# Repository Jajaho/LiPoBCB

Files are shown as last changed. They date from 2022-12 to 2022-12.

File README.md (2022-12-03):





---
## Artifacts

[Docs](https://github.com/Jajaho/LiPoBCB/suites/9631889772/artifacts/460196864)  
[Images](https://github.com/Jajaho/LiPoBCB/suites/9631889772/artifacts/460196866)  
[CAD](https://github.com/Jajaho/LiPoBCB/suites/9631889772/artifacts/460196863)  
[Gerber](https://github.com/Jajaho/LiPoBCB/suites/9631889772/artifacts/460196865)

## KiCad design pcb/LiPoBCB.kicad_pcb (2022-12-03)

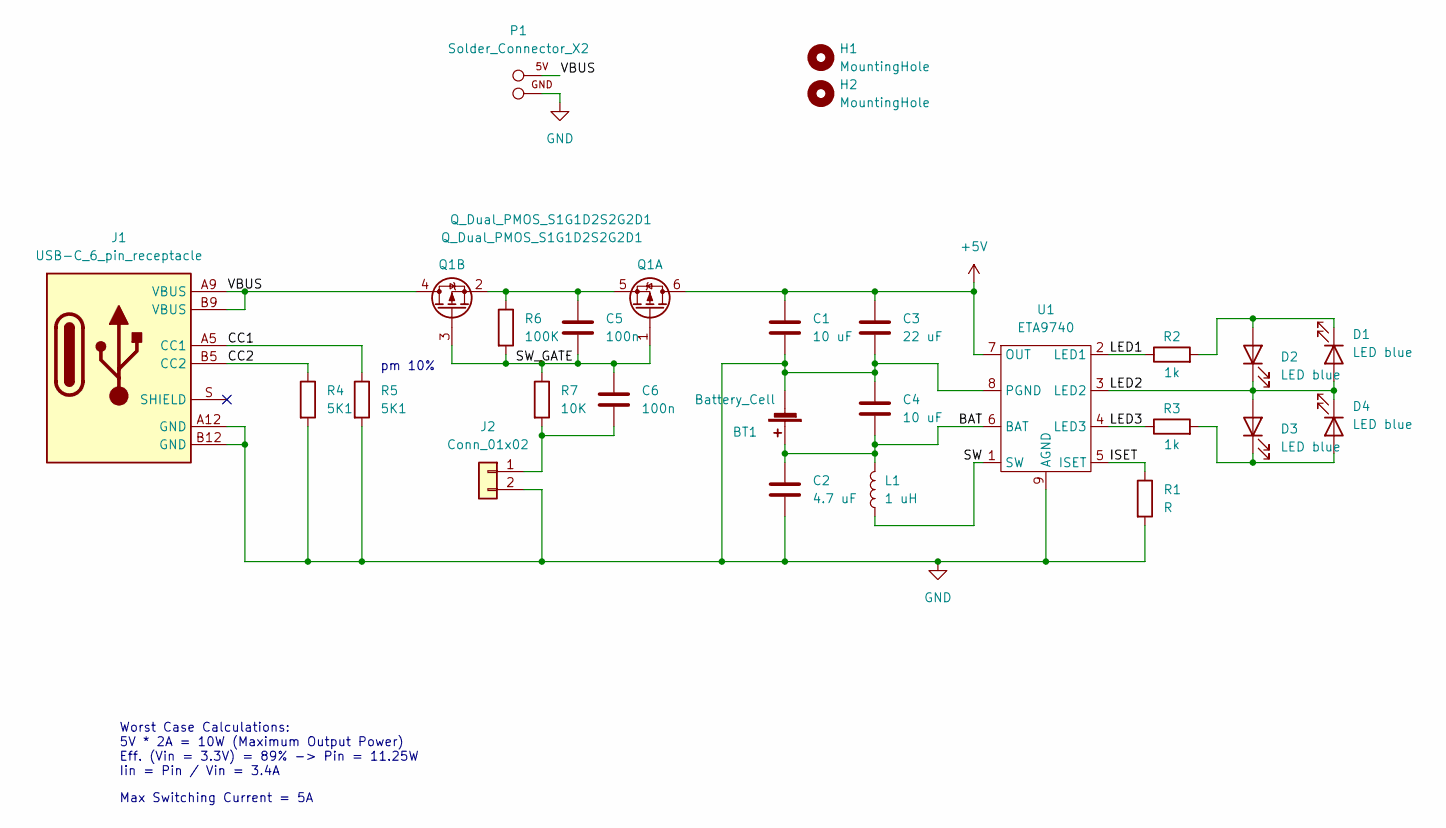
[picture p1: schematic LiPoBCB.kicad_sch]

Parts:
BT1: Battery_Cell; JST_PH_B2B-PH-K_1x02_P2.00mm_Vertical
C1, C4: 10 uF; C_0603_1608Metric
C2: 4.7 uF; C_0603_1608Metric
C3: 22 uF; C_0805_2012Metric
C5, C6: 100n; C_0603_1608Metric
D1, D2, D3, D4: LED blue; D_0603_1608Metric
H1, H2: MountingHole; MountingHole_2.2mm_M2_ISO14580
J1: USB-C_6_pin_receptacle; Korean Hroparts Elec TYPE-C-31-M-17
J2: Conn_01x02; Solder_Connector_SW
L1: 1 uH; L_smd_1616
P1: Solder_Connector_X2
Q1: Q_Dual_PMOS_S1G1D2S2G2D1; SOT-23-6
R1: R; R_0603_1608Metric
R2, R3: 1k; R_0603_1608Metric
R4, R5: 5K1; R_0603_1608Metric
R6: 100K; R_0603_1608Metric
R7: 10K; R_0603_1608Metric
U1: ETA9740; SOIC-8-1EP_3.9x4.9mm_P1.27mm_EP2.29x3mm

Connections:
+5V: C1.1, C3.1, Q1.6 (D), U1.7 (OUT)
/BAT: BT1.1 (+), C2.1, C4.2, L1.2, U1.6 (BAT)
/CC1: J1.A5 (CC1), R5.1
/CC2: J1.B5 (CC2), R4.1
/ISET: R1.1, U1.5 (ISET)
/LED1: R2.1, U1.2 (LED1)
/LED2: D1.2 (A), D2.1 (K), D3.2 (A), D4.1 (K), U1.3 (LED2)
/LED3: R3.1, U1.4 (LED3)
/SW: L1.1, U1.1 (SW)
/SW_GATE: C5.2, C6.1, Q1.1 (G), Q1.3 (G), R6.2, R7.1
/VBUS: J1.A9 (VBUS), J1.B9 (VBUS), P1.1 (5V), Q1.4 (D)
GND: BT1.2 (-), C1.2, C2.2, C3.2, C4.1, J1.A12 (GND), J1.B12 (GND), J2.2, P1.2 (GND), R1.2, R4.2, R5.2, U1.8 (PGND), U1.9 (AGND)
unnamed: C5.1, Q1.2 (S), Q1.5 (S), R6.1
unnamed: C6.2, J2.1, R7.2
unnamed: D1.1 (K), D2.2 (A), R2.2
unnamed: D3.1 (K), D4.2 (A), R3.2

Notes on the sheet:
Worst Case Calculations: 5V * 2A = 10W (Maximum Output Power) Eff. (Vin = 3.3V) = 89% -> Pin = 11.25W Iin = Pin / Vin = 3.4A
pm 10%
Max Switching Current = 5A

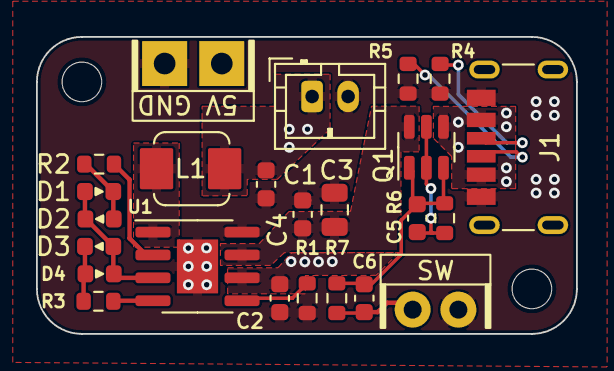
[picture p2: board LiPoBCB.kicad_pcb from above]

Board: 2 copper layers, 30.0 x 16.5 mm, 26 parts (0 on the bottom side), 16 nets.

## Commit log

2022-12-02 replaced pcb files
    [KiBot-CICD-Template.kicad_pcb, KiBot-CICD-Template.kicad_sch, LiPoBCB.kicad_pcb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]
2022-12-03 Update pcb files
    [LiPoBCB.kicad_pcb, LiPoBCB.kicad_sch]
2022-12-03 Updates DRC
    [LiPoBCB.kicad_pcb, LiPoBCB.kicad_sch]
